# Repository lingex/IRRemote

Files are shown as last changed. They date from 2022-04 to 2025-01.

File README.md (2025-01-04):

# IRRemote
ESP32空调遥控器

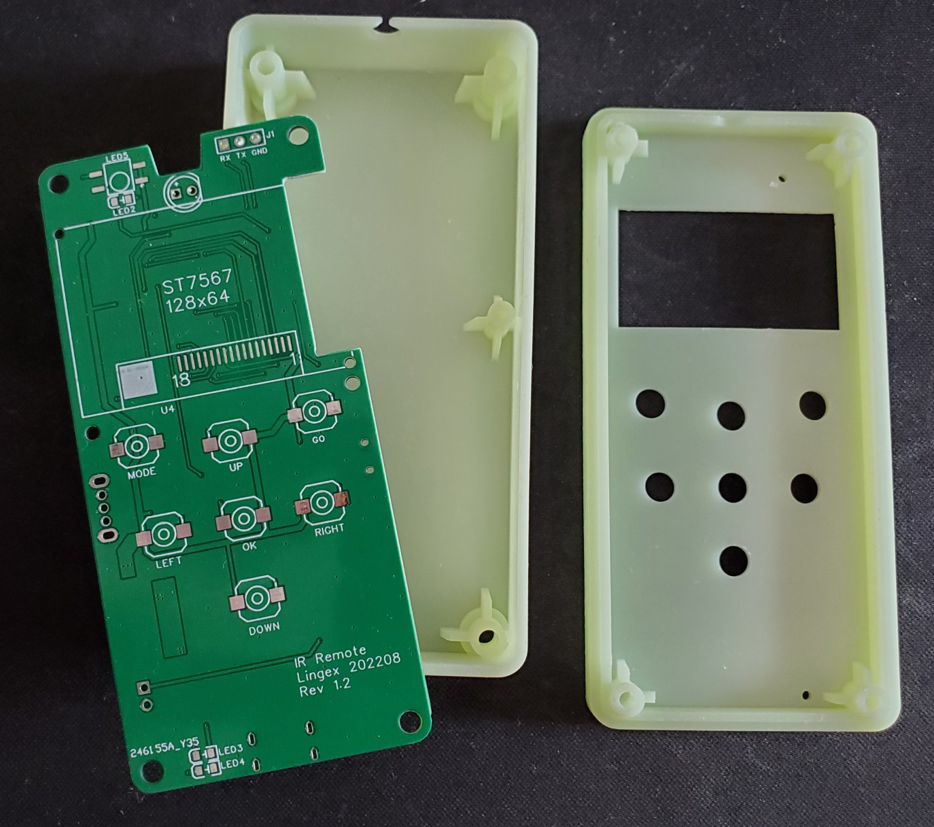
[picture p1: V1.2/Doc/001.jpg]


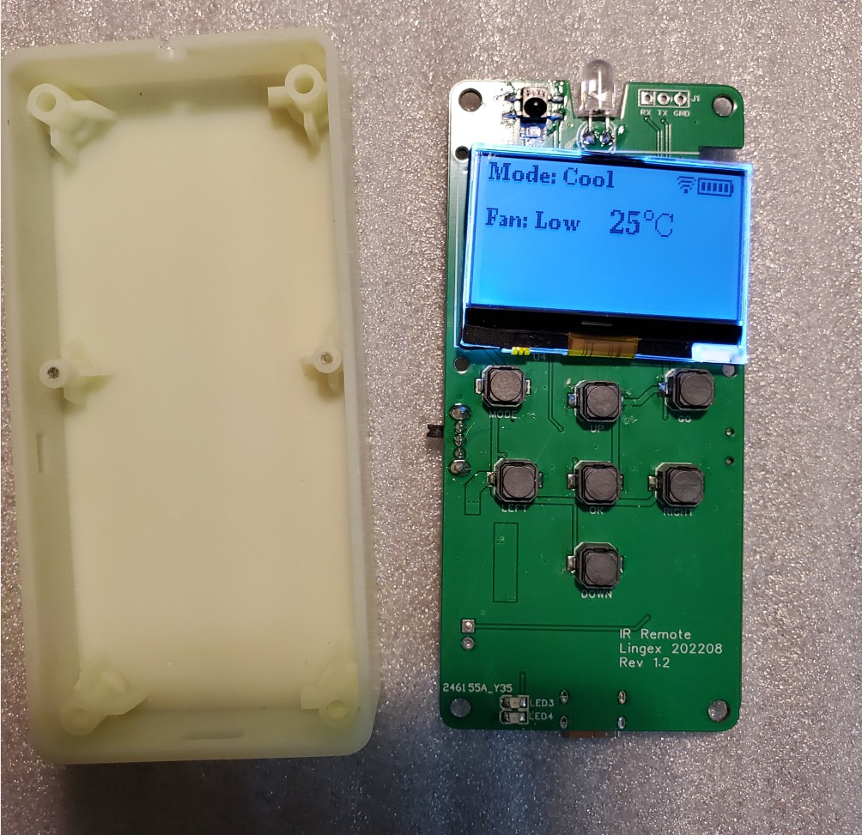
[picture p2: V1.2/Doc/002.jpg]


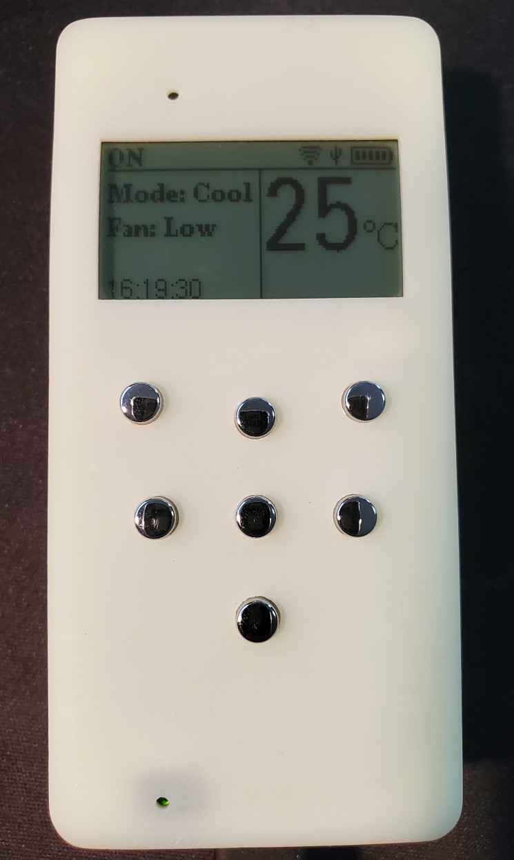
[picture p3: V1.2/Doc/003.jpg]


## 缘由
因为住处原装空调遥控器丢失，后配的万能遥控存在各种问题(重启、失灵等等)，于是只好自己做一个了。

### 特性
可充电 低功耗(待机电流约 90uA) OTA 更新 可扩展 web 控制等

### 存在问题
- I2C SCL(IO2) 端口分配不当，接上 OLED 屏幕后因带有上拉会导致 COM 方式下载失败。解决方法是 COM 方式下载时先拆掉屏幕
- 将 R1 改为 10R，遥控距离还能提升
- 低功耗还可改进，R26 改为 100K, 不需使用学习功能时, 将接收头供电断开可进一步降低功耗
- ~~按键布局不太恰当~~
- ~~web 控制和遥控按键同时使用会导致 web 端逻辑混乱~~， 协议中这个 power 位真是个奇葩的设定, ~~没搞懂它存在的意义~~, 目前看来仅仅是遥控器用来标记开关状态，而非用作控制
- 从 WiFi 开启模式进入 deep sleep 有模组未关闭(约 1.2mA 电流), 唤醒后重新进入会关闭  
- 受限于 LDO 的性能, 待机功耗大概是降不下去了
- V1.2 版电池电压检测部分 Q7 的 D-S 管脚弄反了，影响功耗
- LDO 采用HT7833(V1.1 V1.2)是个巨大的坑，Wi-Fi启动时经常出现供电不足问题，甚至插着USB也不行。

###
红外发射部分是用crankyoldgit/IRremoteESP8266 @ ^2.8.1修改的，调整了命令格式。可能空调版本有分地区，总之与原版的不适配，因此单独拷出来放到 lib 中。

## 鸣谢

参考和使用了不少开源代码和工具，一并表示感谢

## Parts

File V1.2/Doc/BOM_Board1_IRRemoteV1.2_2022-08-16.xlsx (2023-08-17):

No. | Quantity | Device | Designator | Footprint | Value
1 | 1 | HDR-F-2.54_1x2 | BAT1 | HDR-TH_2P-P2.54-V
2 | 3 | 1u_C0603 | C1,C4,C10 | C0603
3 | 1 | 2.2u | C2 | C0603
4 | 15 | 0.1u_C0603 | C3,C5,C6,C7,C11,C12,C13,C14,C15,C16,C17,C19,C20,C21,C22 | C0603
5 | 1 | 10u_C0603 | C8 | C0603
6 | 2 | 10u | C9,C18 | C0805
7 | 1 | 1N5819WS(SL) | D2 | SOD-323_L1.8-W1.3-LS2.5-RD
8 | 6 | 6*6*5 Silicone silent key button_KEY-SMD_L6.0-W6.0-LS6.6_C61120 | DOWN,GO,LEFT,OK,RIGHT,UP | KEY-SMD_L6.0-W6.0-LS6.6_C61120
9 | 3 | CESDBLC5V0D3_SOD-323_L1.8-W1.3-LS2.5-BI | E1,E2,E3 | SOD-323_L1.8-W1.3-LS2.5-BI
10 | 1 | Header-Male-2.54_1x3 | J1 | HDR-TH_3P-P2.54-V-M-1
11 | 1 | LED_TH-R_5mm | LED1 | LED-TH_BD5.8-P2.54-FD
12 | 2 | LED_0805-R | LED2,LED3 | LED0805-RD_RED
13 | 1 | LED_0805-G | LED4 | LED0805-RD_RED
14 | 1 | IRM-H638T/TR2(DX) | LED5 | SENSOR-SMD_IRM-H638T-TR2-DX
15 | 1 | 6*6*5 Silicone silent key button | MODE | KEY-SMD_L6.0-W6.0-LS6.6_C61120
16 | 3 | SI2302 | Q1,Q3,Q6 | SOT-23-3_L2.9-W1.3-P1.90-LS2.4
17 | 2 | SI2301 | Q2,Q7 | SOT-23-3_L2.9-W1.3-P1.90-LS2.4-BR
18 | 1 | SS8050 | Q9 | SOT-23-3_L2.9-W1.3-P1.90-LS2.4-BR
19 | 6 | 36k_R0603 | R1,R14,R15,R29,R30,R31 | R0603
20 | 6 | 1k_R0603 | R2,R7,R11,R12,R18,R28 | R0603
21 | 1 | 22R | R3 | R0603
22 | 1 | 5k1 | R4 | R0603
23 | 1 | 5k1_R0603 | R5 | R0603
24 | 1 | 10R | R6 | R0603
25 | 3 | 10k_R0603 | R8,R9,R16 | R0603
26 | 1 | 5k3 | R10 | R0603
27 | 1 | 10k | R13 | R0603
28 | 1 | 1k | R17 | R0603
29 | 1 | 36k | R19 | R0603
30 | 2 | 470R | R20,R21 | R0603
31 | 1 | 20k | R22 | R0603
32 | 5 | 20k_R0603 | R23,R24,R25,R26,R27 | R0603
33 | 1 | 7k5 | RP1 | R0603
34 | 1 | SK12D07VG3 | SW1 | SW-TH_SK12D07VG3
35 | 1 | UK-B0261-AQ25Y | SW2 | KEY-SMD_UK-B0261-AQ25Y
36 | 1 | HT7833 | U1 | SOT-89_L4.5-W2.5-P1.50-LS4.2-BR
37 | 1 | ESP32-WROOM-32UE-N16 | U2 | WIFI-SMD_ESP32-WROOM-32UE
38 | 1 | TP4057 | U3 | SOT-23-6_L2.9-W1.6-P0.95-LS2.8-BR
39 | 1 | FM1922570CT6-00 | U4 | FM1922570CT6-00
40 | 1 | TYPEC-250D-BCP6 | USB1 | USB-C-SMD_TYPEC-250D-BCP6

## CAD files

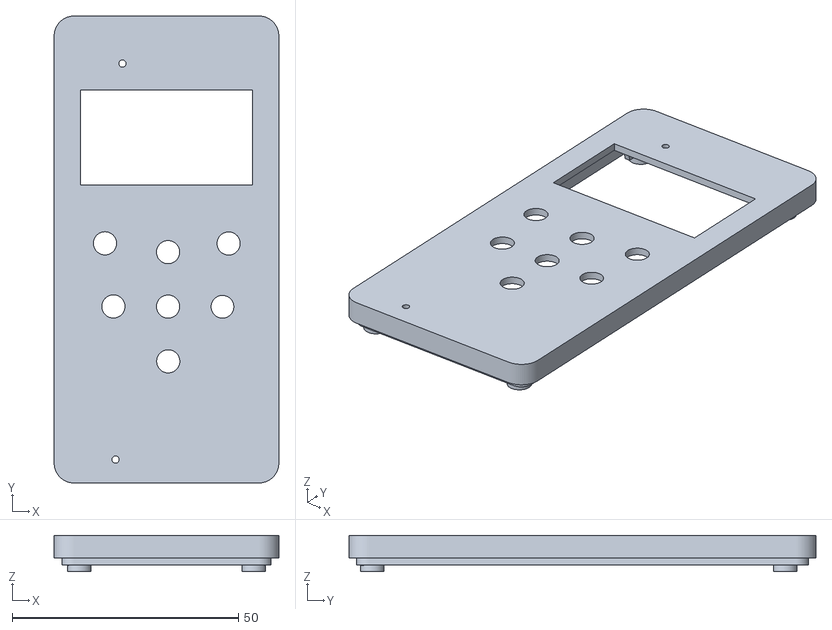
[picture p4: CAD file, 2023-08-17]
V1.2/Doc/3DShell_PCB_IRRemoteV1.2_T.stl
49.6 x 103.1 x 8.00

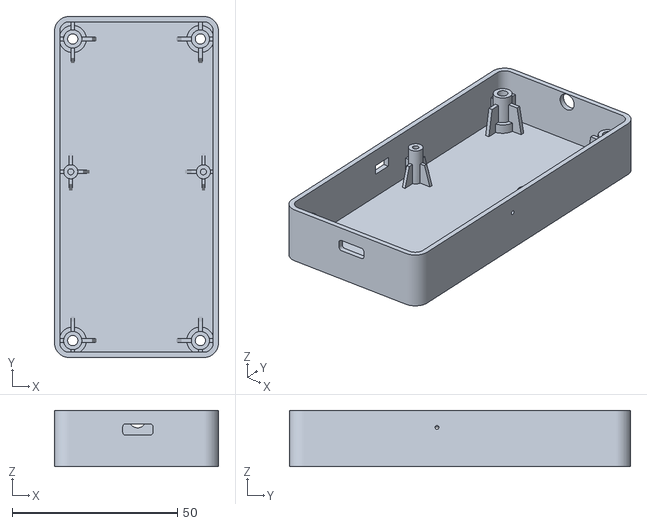
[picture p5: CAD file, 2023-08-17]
V1.2/Doc/3DShell_PCB_IRRemoteV1.2_B.stl
49.6 x 103.1 x 17.0

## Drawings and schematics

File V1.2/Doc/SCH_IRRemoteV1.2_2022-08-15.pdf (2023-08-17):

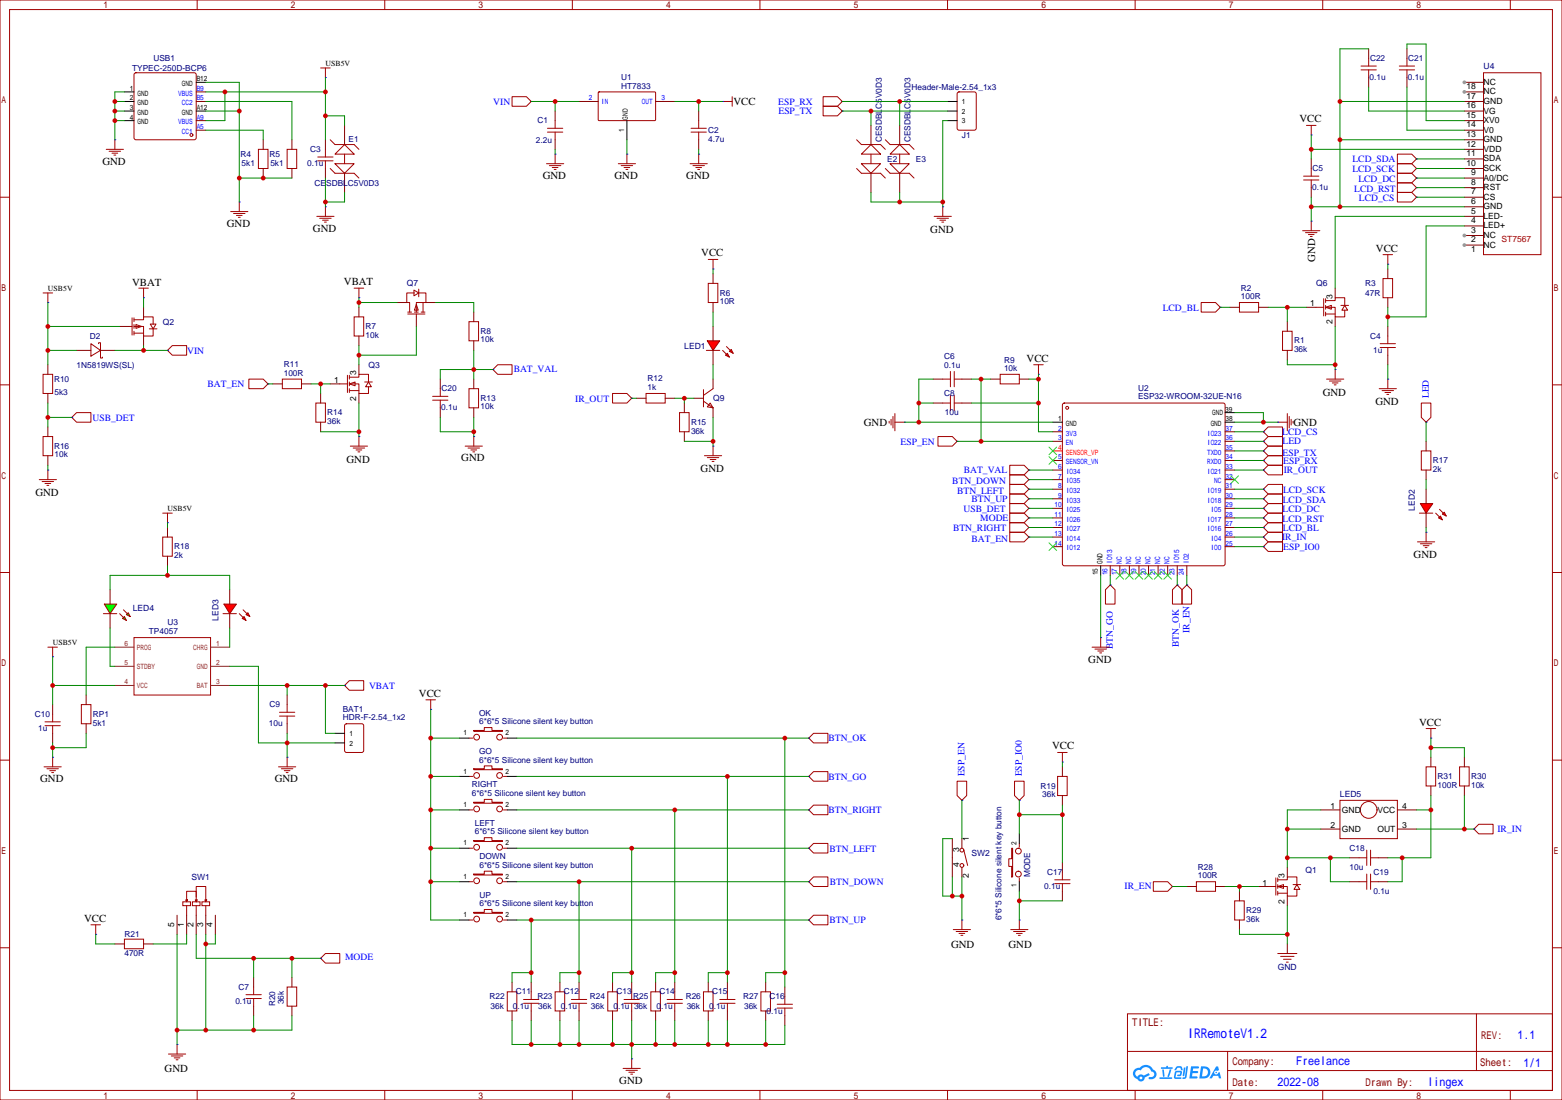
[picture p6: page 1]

6*6*5 Silicone silent key button

RIGHT

LEFT

DOWN

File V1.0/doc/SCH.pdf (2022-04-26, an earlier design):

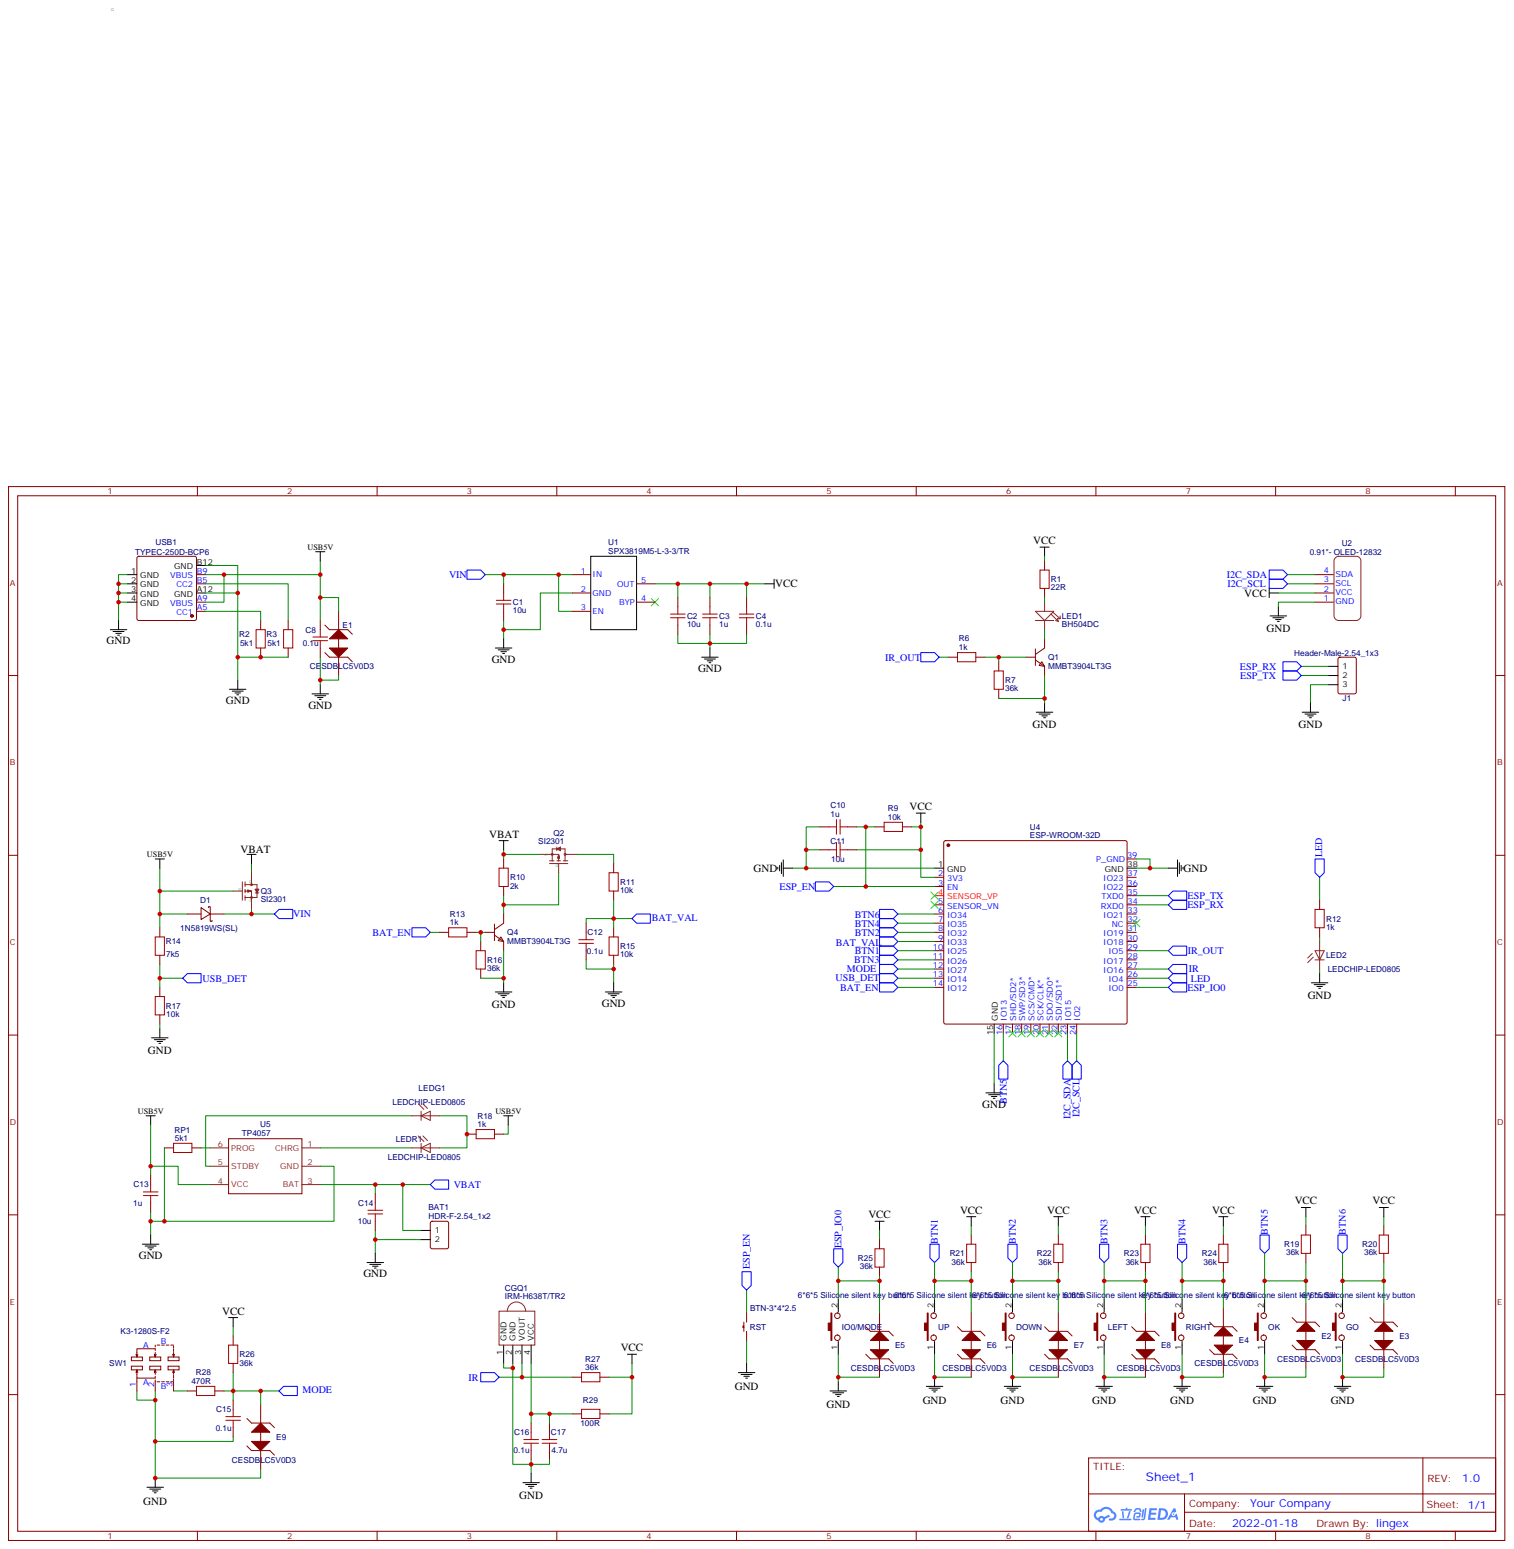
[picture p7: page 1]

CC1 A5 VBUS A9 GND A12 CC2 B5 VBUS B9 GND B12

6*6*5 Silicone silent key button

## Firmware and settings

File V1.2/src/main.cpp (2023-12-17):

#include <Wire.h>
#include <SPI.h>
#include <WiFi.h>
#include <string>
#include <WiFiServer.h>
#include <ESPmDNS.h>
#include <FS.h>
#include <SPIFFS.h>
#include <ArduinoJson.h>
#include <ArduinoOTA.h>
#include <IRremoteESP8266.h>
#include <IRrecv.h>
#include <IRutils.h>
#include <IRsend.h>
#include <IRac.h>
#include <IRtext.h>
#include "WiFiManager.h"
#include <NTPClient.h>
#include <WiFiUdp.h>
#include <OneButton.h>

#include "main.h"
#include "ota.h"
#include "rtc_io.h"
#include "web.h"
#include "config.h"	//please define your wifi ssid and passwd here, avoid to share it on the Internet

#include <U8g2lib.h>

#include <ir_Hitachi.h>

#include <vector>
#include <map>

using namespace std;

#define SW_ACTIVE (digitalRead(SW_PIN) == 0)
#define USB_ACTIVE (digitalRead(USB_DET) == 1)
#define OK_ACTIVE (digitalRead(KEY_OK) == 1)

#define BAT_SAMPLE_ON  (digitalWrite(BAT_ADCEN, 1))
#define BAT_SAMPLE_OFF (digitalWrite(BAT_ADCEN, 0))

#define DIS_BL_ON  (digitalWrite(DIS_BL, 1))
#define DIS_BL_OFF (digitalWrite(DIS_BL, 0))

#define IR_IN_PWR_ON  (digitalWrite(IR_IN_EN, 1))
#define IR_IN_PWR_OFF (digitalWrite(IR_IN_EN, 0))


const char* host = "esp32";
const char* ssid = WIFI_SSID;
const char* password = WIFI_PASSWORD;
const char* apssid      = "esp32";
const char* appassword = "pwd4admin";
uint64_t chipid;

int64_t btnChkMs = 0;
int connLostCnt = 0;

const uint16_t lowestBatVol = 3450;	//protect battery voltage

static std::map<uint32_t, uint32_t> batVolIconMap = 
{
	//<voltage, index>
	{4050, 5},
	{3980, 4},
	{3850, 3},
	{3780, 2},
	{3620, 1},
	{0, 0,  }
};

//U8G2_ST7565_ZOLEN_128X64_F_4W_SW_SPI u8g2(U8G2_R0, DIS_SCK, DIS_SDA, DIS_CS, DIS_DC, DIS_RST);
//U8G2_ST7565_LX12864_F_4W_SW_SPI u8g2(U8G2_R0, DIS_SCK, DIS_SDA, DIS_CS, DIS_DC, DIS_RST);
U8G2_ST7565_ERC12864_ALT_F_4W_SW_SPI u8g2(U8G2_R0, DIS_SCK, DIS_SDA, DIS_CS, DIS_DC, DIS_RST);

// GPIO to use to control the IR LED circuit. Recommended: 4 (D2).
const uint16_t kIrLedPin = IR_OUT;

// The IR transmitter.
IRHitachiAc1 ac(kIrLedPin);

WiFiUDP ntpUDP;
NTPClient timeClient(ntpUDP, "time.nist.gov", 8 * 3600, 300 * 1000);
WiFiServer server(80);

std::vector<OneButton> buttons = {
	OneButton(KEY_BOOT, true, false),
	OneButton(KEY_GO, false, false),
	OneButton(KEY_UP, false, false),
	OneButton(KEY_DOWN, false, false),
	OneButton(KEY_LEFT, false, false),
	OneButton(KEY_RIGHT, false, false),
	OneButton(KEY_OK, false, false)
};

uint32_t batteryVol = 0;	//battary voltage in mV
uint16_t idleClock = 0;
uint16_t blClock = 0;
const uint16_t cfgSleepSec = 15;

//RTC_DATA_ATTR uint8_t acMode = 0;
uint32_t upCount = 0;

void handleModeInt();
void handleOkInt();
void handleUpInt();
void handleDownInt();
void handleLeftInt();
void handleRightInt();

void ButtonEventsAttach();
void printState();
void printLCD();
uint32_t GetBatteryVol();

void ButtonActionGo();
void ButtonActionOk();
void ButtonActionMode();
void ButtonActionUp();
void ButtonActionDown();
void ButtonActionLeft();
void ButtonActionRight();
void LowBatteryAction();
void AcCmdSend();
void AcSwingVSwitch();
void AcPowerToggle();
String GetDeviceInfoString();

String AcModeString(uint8_t mode)
{
	String result = "UNKNOW";
	switch (mode)
	{
	case kHitachiAc1Cool:
		result = "Cool";
		break;
	case kHitachiAc1Heat:
		result = "Heat";
		break;
	case kHitachiAc1Dry:
		result = "Dry";
		break;
	case kHitachiAc1Fan:
		result = "Fan";
		break;
	case kHitachiAc1Auto:
		result = "Auto";
		break;
	default:
		break;
	}
	return result;
}

String AcFanString(uint8_t speed)
{
	String result = "UNKNOW";
	switch (speed)
	{
	case kHitachiAc1FanHigh:
		result = "High";
		break;
	case kHitachiAc1FanMed:
		result = "Med";
		break;
	case kHitachiAc1FanLow:
		result = "Low";
		break;
	case kHitachiAc1FanAuto:
		result = "Auto";
		break;
	default:
		break;
	}
	return result;
}

/*
Method to print the reason by which ESP32
has been awaken from sleep
*/
void print_wakeup_reason()
{
	esp_sleep_wakeup_cause_t wakeup_reason = esp_sleep_get_wakeup_cause();

	switch(wakeup_reason)
	{
		case ESP_SLEEP_WAKEUP_EXT0:
		{
			Serial.println("Wakeup caused by external signal using RTC_IO");
		}
		break;
		case ESP_SLEEP_WAKEUP_EXT1:
		{
			Serial.println("Wakeup caused by external signal using RTC_CNTL");
		}
		break;
		case ESP_SLEEP_WAKEUP_TIMER:
		{
			Serial.println("Wakeup caused by timer");
		}
		break;
		case ESP_SLEEP_WAKEUP_TOUCHPAD:
		{
			Serial.println("Wakeup caused by touchpad");
		}
		break;
		case ESP_SLEEP_WAKEUP_ULP:
		{
			Serial.println("Wakeup caused by ULP program");
		}
		break;
		default:
		{
			Serial.printf("Wakeup was not caused by deep sleep: %d\n",wakeup_reason);
		}
		break;
	}
}

String acPowerState()
{
	return (ac.getPower() ? "checked" : "");
}

String GetContentType(String filename)
{
  //if(server.hasArg("download")) return "application/octet-stream";
  if(filename.startsWith("/u/")) return "application/octet-stream";
  else if(filename.endsWith(".htm")) return "text/html";
  else if(filename.endsWith(".html")) return "text/html";
  else if(filename.endsWith(".css")) return "text/css";
  else if(filename.endsWith(".js")) return "application/javascript";
  else if(filename.endsWith(".png")) return "image/png";
  else if(filename.endsWith(".gif")) return "image/gif";
  else if(filename.endsWith(".jpg")) return "image/jpeg";
  else if(filename.endsWith(".ico")) return "image/x-icon";
  else if(filename.endsWith(".xml")) return "text/xml";
  else if(filename.endsWith(".pdf")) return "application/x-pdf";
  else if(filename.endsWith(".zip")) return "application/x-zip";
  else if(filename.endsWith(".gz")) return "application/x-gzip";
  return "text/plain";
}
/*
void OnNotFound(AsyncWebServerRequest *request)
{
  String message = "";
  String path = request->url();
  Serial.print("request to: " + path + "\n");
  String contentType = GetContentType(path);
  String pathWithGz = path + ".gz";
  if(SPIFFS.exists(pathWithGz) || SPIFFS.exists(path))
  {
    if(SPIFFS.exists(pathWithGz))
	{
      path += ".gz";
    }
	AsyncWebServerResponse *response =  request->beginResponse(SPIFFS, path, contentType);
	request->send(response);
    return;
  }

  Serial.print("File not Found:");
  Serial.println(path);
  message += "404 The content you are looking for was not found.\n\n";
  message += "Path: ";
  message += path;
  message += "\nMethod: ";
  message += (request->method() == HTTP_GET) ? "GET" : "POST";
  message += "\nArgs: ";
  message += request->args();
  message += "\n";
  for(uint8_t i = 0; i < request->args(); i++)
  {
    message += " " + request->argName(i) + ": " + request->arg(i) + "\n";
  }
  request->send_P(404, "text/plain", message.c_str());
}
*/

String GetSpiffsFile(String fileName)
{
  String message = "";
  String path = fileName;
  Serial.print("request to: " + path + "\n");
  String contentType = GetContentType(fileName);
  String pathWithGz = path + ".gz";
  if(SPIFFS.exists(pathWithGz) || SPIFFS.exists(path))
  {
    if(SPIFFS.exists(pathWithGz))
	{
      path += ".gz";
    }
	File file = SPIFFS.open(path, FILE_READ);
	char *buf = new char[file.size()];
	memset(buf, 0, file.size());
	file.readBytes(buf, file.size());

	String str = String(buf);
	delete[] buf;
    return str;
  }
  return "";
}

bool ConnectWiFi(String ssid,String pwd)
{
	Serial.println("Trying WiFi: " + ssid);
	int connectCount = 0;
	WiFi.begin(ssid.c_str(), pwd.c_str());
	while(!WiFi.isConnected() && connectCount++ < 9)
	{
		delay(500);
		Serial.print(".");
	}
	if(WiFi.isConnected())
	{
		Serial.println("");
		Serial.print("Connected to WiFi: ");
		Serial.println(ssid);
		Serial.print("IP address: ");
		Serial.println(WiFi.localIP());
		connectCount = 0;
		WiFi.setAutoReconnect(true);
		MDNS.addService("http", "tcp", 80);
		return true;
	}
	Serial.println("Connect fail!");
	return false;
}

void setup()
{
	pinMode(LED, OUTPUT);
	digitalWrite(LED, 1);

	// Setup serial interface
	Serial.begin(115200);

	if (SW_ACTIVE)
	{
		print_wakeup_reason();
	}

	/*After waking up from sleep, the IO pad used for wakeup will be configured as RTC IO. 
	Therefore, before using this pad as digital GPIO, 
	users need to reconfigure it using rtc_gpio_deinit() function.
	*/
	rtc_gpio_deinit((gpio_num_t)KEY_BOOT);
	rtc_gpio_deinit((gpio_num_t)KEY_OK);
	rtc_gpio_deinit((gpio_num_t)SW_PIN);
	rtc_gpio_deinit((gpio_num_t)KEY_GO);
	rtc_gpio_deinit((gpio_num_t)KEY_UP);
	rtc_gpio_deinit((gpio_num_t)KEY_DOWN);
	rtc_gpio_deinit((gpio_num_t)KEY_LEFT);
	rtc_gpio_deinit((gpio_num_t)KEY_RIGHT);
	gpio_hold_dis((gpio_num_t)DIS_RST);

	pinMode(SW_PIN, INPUT);
	pinMode(USB_DET, INPUT);
	pinMode(BAT_ADCEN, OUTPUT);
	pinMode(DIS_BL, OUTPUT);
	BAT_SAMPLE_OFF;


	//Serial.printf("AC model:%s.\n", "R_LT0541_HTA_B");
	ac.begin();
	ac.setModel(R_LT0541_HTA_B);
	ac.setSleep(0);
	ac.setPower(false);
	ac.setPowerToggle(false);
	ac.setSwingToggle(false);
	ac.setSwingH(false);
	ac.setSwingV(false);

	ac.setMode(kHitachiAc1Cool);
	ac.setTemp(kHitachiAc1TempAuto);
	ac.setFan(kHitachiAc1FanLow);

	u8g2.begin();
	u8g2.setFont(u8g2_font_ncenB12_tr);	// choose a suitable font
	u8g2.drawStr(18, 20, "AC Remote");	// write something to the internal memory

	u8g2.sendBuffer();	// transfer internal memory to the display

	DIS_BL_ON;

	if (SW_ACTIVE)
	{
		WiFi.setHostname(HOST_NAME);
		ConnectWiFi(ssid, password);
		if(!WiFi.isConnected())
		{
			WiFiManager wifiManager;

			wifiManager.resetSettings();
			//in seconds
			wifiManager.setTimeout(300);
			
			//set custom ip for portal
			//wifiManager.setAPStaticIPConfig(IPAddress(10,0,1,1), IPAddress(10,0,1,1), IPAddress(255,255,255,0));

			//fetches ssid and pass from eeprom and tries to connect
			//if it does not connect it starts an access point with the specified name
			//here  "AutoConnectAP"
			//and goes into a blocking loop awaiting configuration
			if (wifiManager.autoConnect(apssid, appassword))
			{
				Serial.println("failed to connect and hit timeout");
				delay(3000);
				//reset and try again, or maybe put it to deep sleep
				ESP.restart();
			}
			//or use this for auto generated name ESP + ChipID
			//wifiManager.autoConnect();
		}

		server.begin();
		openOTA();

		/*use mdns for host name resolution*/
		if (!MDNS.begin(host))
		{ //http://esp32.local
			Serial.println("Error setting up MDNS responder!");
			while (1) 
			{
				delay(1000);
			}
		}
		Serial.println("mDNS responder started");

		timeClient.begin();
		timeClient.update();
	}

	chipid=ESP.getEfuseMac();//The chip ID is essentially its MAC address(length: 6 bytes).
	Serial.printf("ESP32 Chip ID = %04X",(uint16_t)(chipid>>32));//print High 2 bytes
	Serial.printf("%08X\n",(uint32_t)chipid);//print Low 4bytes.

	ButtonEventsAttach();

	batteryVol = GetBatteryVol();

	printState();
	digitalWrite(LED, 0);
}


uint8_t GetBatteryIndex()
{
	int64_t curSec = millis() / 1000;
	uint8_t index = 0;
	static uint8_t chargeStep;
	static int64_t lastSec = curSec;

	for (auto it = batVolIconMap.rbegin(); it != batVolIconMap.rend(); it++)
	{
		if (batteryVol >= it->first)
		{
			index = it->second;
			break;
		}
	}
	if (USB_ACTIVE && batVolIconMap.size() > 0)	//charging
	{
		if (curSec != lastSec)
		{
			lastSec = curSec;
			if (chargeStep < index)
			{
				chargeStep = index;
			}
			chargeStep++;
			if (chargeStep >= batVolIconMap.size())
			{
				chargeStep = index;
			}
			index = chargeStep;
		}
	}

	return index;
}


void printLCD()
{
	u8g2.clearBuffer();

	//POWER STATE
	u8g2.setFont(u8g2_font_ncenB08_tr);
	u8g2.setCursor(0, 9);
	u8g2.printf("%s", ac.getPower() ? "ON" : "OFF");

	//MODE
	u8g2.setCursor(0, 24);
	u8g2.printf("Mode: %s", AcModeString(ac.getMode()).c_str());

	//lines
	u8g2.drawLine(0, 10, 127, 10);
	u8g2.drawLine(67, 10, 67, 63);

	//FAN SPEED
	u8g2.setCursor(0, 38);
	u8g2.printf("Fan: %s", AcFanString(ac.getFan()).c_str());

	//BAT VOLTAGE
	//u8g2.setCursor(1, 48);
	//u8g2.printf("Bat: %dmV", batteryVol);

	uint8_t iconPlace = 95;
	const uint8_t iconDis = 12;

	//battery icon
	{
		u8g2.setFont(u8g2_font_battery19_tn);
		u8g2.setFontDirection(1);
		u8g2.drawGlyph(107, 1, 0x0030 + GetBatteryIndex());
		u8g2.setFontDirection(0);
	}
	//usb icon
	if (USB_ACTIVE)
	{
		u8g2.setFont(u8g2_font_siji_t_6x10);
		u8g2.drawGlyph(iconPlace, 9, 0xe00c); // USB
		iconPlace -= iconDis;
	}
	//wifi icon
	if (WiFi.isConnected())
	{
		u8g2.setFont(u8g2_font_siji_t_6x10);
		u8g2.drawGlyph(iconPlace, 9, 0xe21a); // WIFI
		iconPlace -= iconDis;
	}
	//sleep countdown
	if (idleClock > 0)
	{
		u8g2.setCursor(116, 63);
		u8g2.setFont(u8g2_font_helvR08_tr);
		u8g2.printf("%02d", cfgSleepSec - idleClock);
	}
	//TEMPERATURE
	u8g2.setFont(u8g2_font_fur30_tr);
	u8g2.setCursor(68, 44);
	u8g2.printf("%d", ac.getTemp());
	u8g2.setFont(u8g2_font_cu12_t_symbols);
	u8g2.drawGlyph(112, 44, 0x2103);	// ℃

	//ntp time
	if (SW_ACTIVE)
	{
		u8g2.setCursor(0, 63);
		u8g2.setFont(u8g2_font_helvR08_tr);
		u8g2.printf("%02d:%02d:%02d", timeClient.getHours(), timeClient.getMinutes(), timeClient.getSeconds());
	}

	u8g2.sendBuffer();
}

void printState()
{
	printLCD();

	// Display the settings.
	Serial.println("Remote state: ");
	Serial.printf("  %s\n", ac.toString().c_str());
	// Display the encoded IR sequence.
	unsigned char* ir_code = ac.getRaw();
	Serial.print("IR Code: 0x");
	for (uint8_t i = 0; i < kHitachiAc1StateLength; i++)
	{
		Serial.printf("%02X", ir_code[i]);
	}
	Serial.println();
}

//battery voltage in mV
uint32_t GetBatteryVol()
{
	const uint16_t fixVal = 25;//mV
	static vector<uint16_t> adcVec;
	uint32_t count = 0;

	BAT_SAMPLE_ON;
	delay(6);
	//adcVec.push_back(analogRead(BAT_ADC));
	adcVec.push_back(analogReadMilliVolts(BAT_ADC) - fixVal);
	BAT_SAMPLE_OFF;

	if (adcVec.size() > 5)
	{
		adcVec.erase(adcVec.begin());
	}
	for (auto const &it : adcVec)
	{
		count += it;
	}

	//Serial.printf("size: %d, count: %d\n", adcVec.size(), count);
	count = count * 2 / adcVec.size();
	return count;
}

void loop()
{
	int64_t curMs = millis();
	static int64_t lastRefresh = 0;
	int64_t epochMills = curMs - lastRefresh;

	if (lastRefresh == 0 || epochMills >= 1000)
	{
		lastRefresh = curMs;
		batteryVol = GetBatteryVol();
		//Serial.printf("batVal: %dmV\n", batteryVol);
		if (!SW_ACTIVE)
		{
			if (batteryVol < lowestBatVol && !USB_ACTIVE)
			{
				LowBatteryAction();
			}
			idleClock++;
			blClock = 0;
			Serial.printf("Going to sleep in: %d Sec.\n", cfgSleepSec - idleClock);
		}
		else
		{
			idleClock = 0;
			blClock++;
		}
		printLCD();
	}
	if (curMs - btnChkMs >= 10)
	{
		btnChkMs = curMs;
		for (auto &it : buttons)
		{
			it.tick();
		}
	}

	if (SW_ACTIVE)
	{
		WebHandle();
		if (idleClock != 0 && !WiFi.isConnected())
		{
			u8g2.clearDisplay();
			u8g2.setFont(u8g2_font_ncenB08_tr);
			u8g2.setCursor(28, 18);
			u8g2.println("Going to restart");
			u8g2.sendBuffer();
			Serial.println("\nGoing to restart by SW active!");
			delay(100);
			ESP.restart();
		}
		//server.handleClient();
		ArduinoOTA.handle();
		timeClient.update();
		if (!WiFi.isConnected())
		{
			if (connLostCnt++ >= 180)
			{
				Serial.println("\nWifi connect lost");
				WiFi.reconnect();
				connLostCnt = 0;
			}
		}
		else
		{
			connLostCnt = 0;
		}
		if (blClock == cfgSleepSec)
		{
			DIS_BL_OFF;
			//AcBackup();
		}
	}
	else if (idleClock >= cfgSleepSec)
	{
		u8g2.clearDisplay();
		u8g2.setFont(u8g2_font_ncenB08_tr);
		u8g2.setCursor(28, 18);
		u8g2.println("Going to sleep");
		u8g2.sendBuffer();
		//AcBackup();

		Serial.println("Going to sleep now");
		Serial.flush();

		esp_sleep_enable_timer_wakeup(1000 * 1000);	//delay(1000)
		esp_light_sleep_start();

		//power off oled
		u8g2.noDisplay();
		DIS_BL_OFF;

		//wait until button release
		while (OK_ACTIVE)
		{
			esp_sleep_enable_timer_wakeup(100 * 1000);	//wakeup every 100 millisec
			esp_light_sleep_start();
			yield();
		}

		gpio_hold_en((gpio_num_t)DIS_RST);//cost about 200uA if not doing this
		gpio_deep_sleep_hold_en();

		//esp_sleep_enable_ext0_wakeup((gpio_num_t)KEY_BOOT, 0);	//can wake only when rtc active
		esp_sleep_enable_ext0_wakeup((gpio_num_t)SW_PIN, 0);	//can wake only when rtc active

		uint64_t mask = 0;
		mask |= ((1ull << KEY_OK) | (1ull << KEY_GO) | (1ull << KEY_RIGHT) | (1ull << KEY_LEFT) | (1ull << KEY_UP) | (1ull << KEY_DOWN));
		esp_sleep_enable_ext1_wakeup(mask, ESP_EXT1_WAKEUP_ANY_HIGH);	//can wake when rtc shutdown

		esp_sleep_disable_wakeup_source(ESP_SLEEP_WAKEUP_TIMER);
		esp_deep_sleep_start();
	}
	yield();

	if (!SW_ACTIVE && !WiFi.isConnected())
	{
		esp_sleep_enable_timer_wakeup(50 * 1000);	//wakeup every 50 millisec
		esp_light_sleep_start();
	}
}

void AcCmdSend()
{
	printState();
	digitalWrite(LED, 1);
	ac.send();
	digitalWrite(LED, 0);
	//printState();
	blClock = 0;
}

void AcPowerToggle()
{
	//ac.setPowerToggle(true);
	ac.setPower(ac.getPower() ? false : true);
	AcCmdSend();
}

void AcPowerSwitch(bool on)
{
	ac.setPower(on);
	AcCmdSend();
}

void AcSwingVSwitch()
{
	ac.setSwingToggle(true);
	AcCmdSend();
}

void AcFanSpeed()
{
	uint8_t speed = ac.getFan();
	switch (speed)
	{
	case kHitachiAc1FanAuto:
		speed = kHitachiAc1FanLow;
		break;
	case kHitachiAc1FanHigh:
		speed = kHitachiAc1FanAuto;
		break;
		case kHitachiAc1FanMed:
		speed = kHitachiAc1FanHigh;
		break;
		case kHitachiAc1FanLow:
		speed = kHitachiAc1FanMed;
		break;
	default:
		speed = kHitachiAc1FanAuto;
		break;
	}
	ac.setFan(speed);
	AcCmdSend();
}

void AcModeSwitch()
{
	uint8_t acMode = ac.getMode();
	switch (acMode)
	{
	case kHitachiAc1Dry:
		acMode = kHitachiAc1Fan;
		break;
	case kHitachiAc1Fan:
		acMode = kHitachiAc1Cool;
		break;
		case kHitachiAc1Cool:
		acMode = kHitachiAc1Heat;
		break;
		case kHitachiAc1Heat:
		//acMode = kHitachiAc1Auto;	//disable auto mode
		acMode = kHitachiAc1Dry;
		break;
		case kHitachiAc1Auto:
		acMode = kHitachiAc1Dry;
		break;
	default:
		acMode = kHitachiAc1Fan;
		break;
	}

	if (acMode == kHitachiAc1Fan && ac.getFan() == kHitachiAcFanAuto)//auto fan speed not allow in fan mode
	{
		ac.setFan(kHitachiAcFanLow);
	}
	ac.setMode(acMode);
	AcCmdSend();
}

void ButtonActionGo()
{
	idleClock = 0;
	blClock = 0;
	Serial.println("BTN GO CLICK");
	AcPowerToggle();
}
void ButtonActionOk()
{
	idleClock = 0;
	Serial.println("BTN OK CLICK");

	{
		DIS_BL_ON;
	}
}
void ButtonActionLongOk()
{
	Serial.println("BTN OK HOLD");
	if (!SW_ACTIVE)
	{
		idleClock = cfgSleepSec;
	}
	else
	{
		DIS_BL_OFF;
	}
}
void ButtonActionMode()
{
	idleClock = 0;
	Serial.println("BTN MODE CLICK");
	AcModeSwitch();
}
void ButtonActionUp()
{
	idleClock = 0;
	Serial.println("BTN UP CLICK");
	ac.setTemp(ac.getTemp() + 1);
	AcCmdSend();
}
void ButtonActionDown()
{
	idleClock = 0;
	Serial.println("BTN DOWN CLICK");
	ac.setTemp(ac.getTemp() - 1);
	AcCmdSend();
}
void ButtonActionLeft()
{
	idleClock = 0;
	Serial.println("BTN LEFT CLICK");
	AcSwingVSwitch();
}
void ButtonActionRight()
{
	idleClock = 0;
	Serial.println("BTN RIGHT CLICK");
	AcFanSpeed();
}

void ButtonEventsAttach()
{
	Serial.println("BTN ATTACHED");
	if (buttons.size() < 1)
	{
		Serial.println("BTN SIZE ERR");
		return;
	}

/*
	OneButton(KEY_BOOT),
	OneButton(KEY_GO),
	OneButton(KEY_UP),
	OneButton(KEY_DOWN),
	OneButton(KEY_LEFT),
	OneButton(KEY_RIGHT),
	OneButton(KEY_OK)
*/
	// mode
	buttons[0].attachClick([] {
		ButtonActionMode();
	});
	buttons[0].setClickTicks(10);
	buttons[1].attachClick([]{  //GO
		ButtonActionGo();
	});
	buttons[2].attachClick([]{  //UP
		ButtonActionUp();
	});
	buttons[3].attachClick([]{  //DOWN
		ButtonActionDown();
	});
	buttons[4].attachClick([]{  //LEFT
		ButtonActionLeft();
	});
	buttons[5].attachClick([]{  //RIGHT
		ButtonActionRight();
	});
	buttons[6].attachClick([]{  //OK
		ButtonActionOk();
	});
	buttons[6].attachLongPressStart([]{  //OK HOLD
		ButtonActionLongOk();
	});
}

void OTAProgress(uint16_t progress)
{
	if (progress == 1)
	{
		DIS_BL_ON;
		u8g2.display();
	}
	if (progress % 5 != 0)
	{
		return;
	}
	
	u8g2.clearBuffer();
	u8g2.setFont(u8g2_font_ncenB08_tr);
	u8g2.setCursor(30, 20);
	u8g2.println("OTA updating");
	u8g2.setCursor(30, 40);
	u8g2.printf("Progress: %d%%", progress);
	u8g2.sendBuffer();
}

//go into deep sleep only can wake up by charge
void LowBatteryAction()
{
	//power off oled
	u8g2.noDisplay();

	esp_sleep_disable_wakeup_source(ESP_SLEEP_WAKEUP_ALL);

	uint64_t mask = 0;
	mask |=  1ull << USB_DET;
	esp_sleep_enable_ext1_wakeup(mask, ESP_EXT1_WAKEUP_ANY_HIGH);	//can wake when rtc shutdown

	esp_sleep_pd_config(ESP_PD_DOMAIN_MAX, ESP_PD_OPTION_OFF);	//force shutdown rtc power

	esp_deep_sleep_start();
}

String GetDeviceInfoString()
{
	unsigned long seconds = millis() / 1000;
	int days = seconds / (24 * 3600);
	seconds = seconds % (24 * 3600);
	int hours = seconds / 3600;
	seconds = seconds % 3600;
	int minutes = seconds / 60;
	seconds = seconds % 60;

	String uptime = String(days) + "d ";
	if (hours < 10)
	{
		uptime += "0";
	}
	uptime += String(hours) + ":";
	if (minutes < 10)
	{
		uptime += "0";
	}
	uptime += String(minutes) + ":";
	if (seconds < 10)
	{
		uptime += "0";
	}
	uptime += String(seconds);

	String result = "Power round: " + String(upCount);
	result += ", Uptime:" + uptime;
	result += ", Charging: " + String((USB_ACTIVE) ? "yes" : "no");
	result += ", Battery voltage: " + String(batteryVol) + " mV";
	// Display the settings.
	result += ", Remote state: ";
	result += ac.toString().c_str();
	// Display the encoded IR sequence.
	unsigned char* ir_code = ac.getRaw();
	result += ", IR Code: 0x";
	char irHex[8] = {0};
	for (uint8_t i = 0; i < kHitachiAc1StateLength; i++)
	{
		sprintf(irHex, "%02X", ir_code[i]);
		result += String(irHex);
	}
	result += ", Hw ver: " + hw_ver;
	result += ", Sw ver: " + sw_ver;
	result += ", build: " + build_time;

	return result;
}

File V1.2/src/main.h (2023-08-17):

#ifndef __MAIN_H__
#define __MAIN_H__

#include <Arduino.h>

/* ------------------------- CUSTOM GPIO PIN MAPPING ------------------------- */


#define IR_OUT 21
#define BAT_ADC 34
#define BAT_ADCEN 14
#define KEY_BOOT 0
#define KEY_GO 13
#define KEY_UP 33
#define KEY_DOWN 35
#define KEY_LEFT 32
#define KEY_RIGHT 27
#define KEY_OK 15
#define SW_PIN 26
#define USB_DET 25
#define DIS_BL 16
#define DIS_SCK 19
#define DIS_SDA 18
#define DIS_DC 5
#define DIS_RST 17
#define DIS_CS 23
#define LED 22
#define IR_IN 4
#define IR_IN_EN 2

void AcPowerSwitch(bool on);
void OTAProgress(uint16_t progress);

#define HOST_NAME "IrRemote-V1.2"
const String hw_ver = "1.2";
const String sw_ver = "1.2";
const String build_time = String(__DATE__) /*+ ", " + String(__TIME__)*/;

#endif

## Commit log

2022-04-26 first version
    [BOM.xlsx]
2022-04-26 wait for OLED power off before deep sleep
2022-04-28 low power improve
2022-04-29 fan speed restrictions remove
2022-04-29 improve low power
2022-04-29 AC state reset (fix fan speed lost control after woken up from deep sleep)
    [main.cpp]
2022-04-30 AC power switch from web
2022-05-02 power logic, text coordinate adjust and icons
2022-05-02 rename folder
    [BOM.xlsx]
2022-05-03 battery voltage sample, add more icon, change switch mode to improve low power performance
2022-05-06 low battery protect
2022-05-18 swap swingV and power bit (in some case swingV toggle not work)
2022-05-20 swap some IR code bits (fan speed)
2022-05-23 u8g2 driver
2023-08-17 new version
    [3DShell_PCB_IRRemoteV1.2_B.stl, 3DShell_PCB_IRRemoteV1.2_T.stl, BOM.xlsx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]
2024-06-08 device name
2025-01-04 add build time to device info
2025-01-10 change device to json format settings save logic
2026-02-11 basic function except fan speed
